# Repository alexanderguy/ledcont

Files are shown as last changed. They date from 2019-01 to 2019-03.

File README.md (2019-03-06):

# Dimming LED Controller

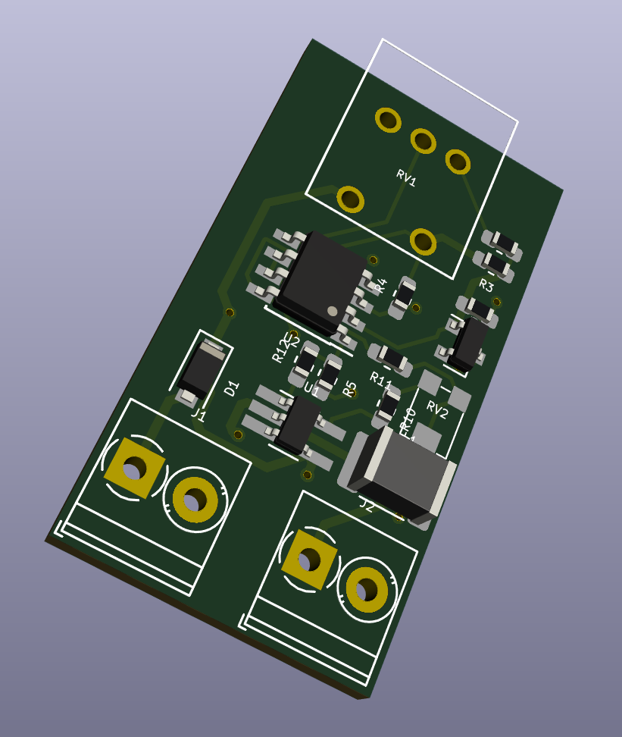
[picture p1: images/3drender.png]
3D Board Rendering


This is a basic dimming LED controller, designed for being run from one or more batteries (~3.25-6 volts).  It includes:

- Analog dimming.
- Low-voltage shutdown.
- Able to run at up to 1A.
- Two-layer board.

It takes about 1.5 hours to assemble if you're: building your first board, finding parts in the process, binging The Americans.

# Modifications

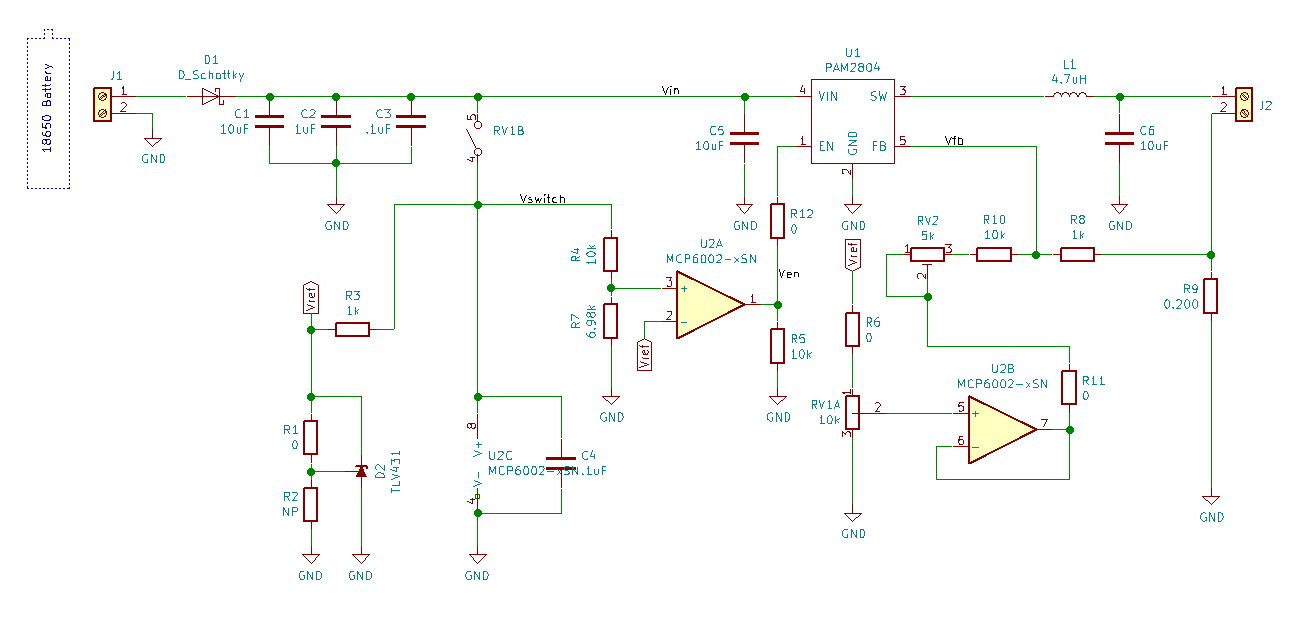
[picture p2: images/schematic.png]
Schematic Preview


There are a number of modifications possible:

- Change R4/R7 to provide the low-voltage shutdown point.
- Tune RV2/R10 to tweak the feedback offset.
- Set maximum current via R9 (see PAM2804 datasheet for more information).
- Don't populate D2/U2/RV1 (and supporting components) if dimming isn't needed (pull-up on EN needed).

# Wiring

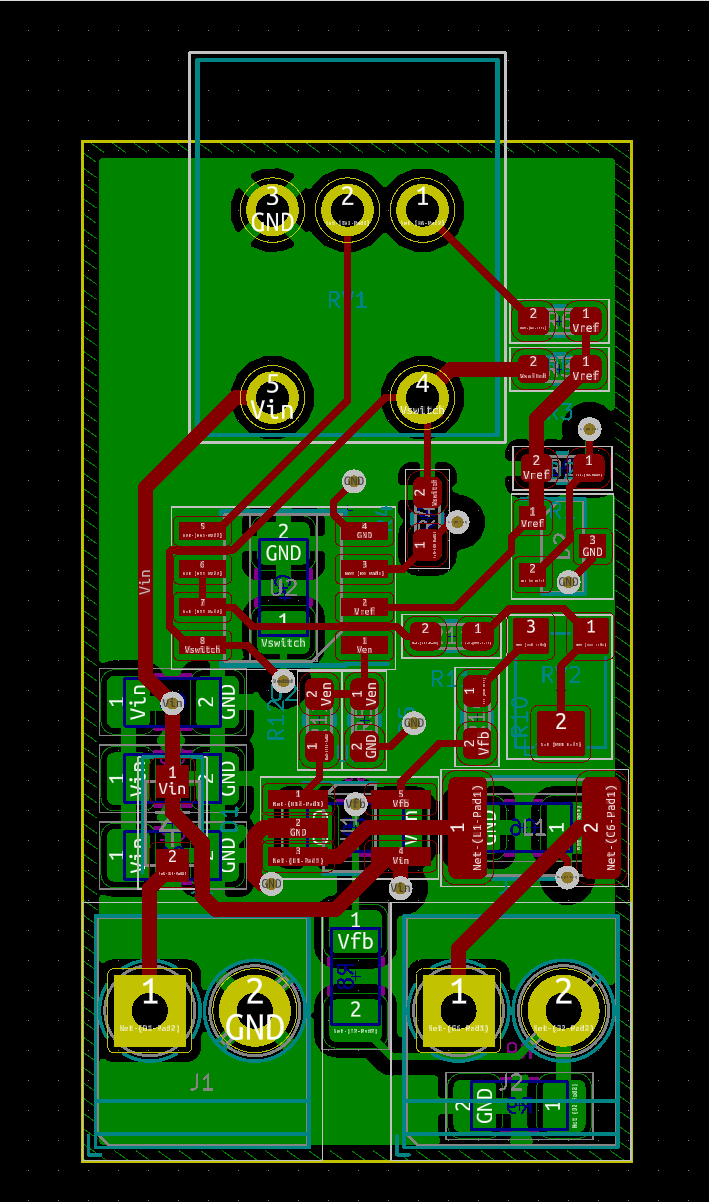
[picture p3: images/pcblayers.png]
PCB Layers


1. Make sure the switching potentiometer is turned off (i.e past the switch detent, counter-clockwise).
2. Attach your LED(s) to J2 Pin 1/+ and J2 Pin 2/-.
3. Attach your power supply to J1 Pin 1/+ and J1 Pin 2/-.

# Dimming Setup

1. Turn the potentiometer on, just past the switch detent.
2. Turn the potentiometer the opposite direction, until resistance is felt.  The LEDs might turn off.
3. If the LEDs are off, adjust RV2 until they are on.
4. If the LEDs were off, adjust RV2 until they just barely turn on.
5. Verify that the potentiometer now gives you complete brightness range for your LEDs.

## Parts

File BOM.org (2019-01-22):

* Possible Parts

| Qty | Part #          | Description                      |
|-----+-----------------+----------------------------------|
|   1 | PAM2804         | LED Driver                       |
|   1 | RL1206FR-070R2L | Current Sense Resistor           |
|   1 | P091S-FC20BR10K | 10k Potentiometer w/ SPST Switch |
|   1 | LQH43PN4R7M26L  | Inductor                         |
|   2 | 1984617         | 2 Pos Terminal Block             |

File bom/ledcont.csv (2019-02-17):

C1 | 10uF | Device:C | Capacitor_SMD:C_1206_3216Metric_Pad1.42x1.75mm_HandSolder | Unpolarized capacitor | CL31B106KOHNFNE
C2 | 1uF | Device:C | Capacitor_SMD:C_1206_3216Metric_Pad1.42x1.75mm_HandSolder | Unpolarized capacitor | CL31B105MAHNNNE
C3 | .1uF | Device:C | Capacitor_SMD:C_1206_3216Metric_Pad1.42x1.75mm_HandSolder | Unpolarized capacitor | CL31B104KBCNNNC
C4 | .1uF | Device:C | Capacitor_SMD:C_1206_3216Metric_Pad1.42x1.75mm_HandSolder | Unpolarized capacitor | CL31B104KBCNNNC
C5 | 10uF | Device:C | Capacitor_SMD:C_1206_3216Metric_Pad1.42x1.75mm_HandSolder | Unpolarized capacitor | CL31B106KOHNFNE
C6 | 10uF | Device:C | Capacitor_SMD:C_1206_3216Metric_Pad1.42x1.75mm_HandSolder | Unpolarized capacitor | CL31B106KOHNFNE
D1 | D_Schottky | Device:D_Schottky | Diode_SMD:D_SOD-123F | Schottky diode | NRVTS245ESFT1G
D2 | TLV431 | Reference_Voltage:TL431DBZ | Package_TO_SOT_SMD:SOT-23 | Shunt Regulator, SOT-23 | TLV431AFTA
J1 | Screw_Terminal_01x02 | Connector:Screw_Terminal_01x02 | TerminalBlock_Phoenix:TerminalBlock_Phoenix_PT-1,5-2-3.5-H_1x02_P3.50mm_Horizontal | Generic screw terminal, single row, 01x02, script generated (kicad-library-utils/schlib/autogen/connector/) | 1984617
J2 | Screw_Terminal_01x02 | Connector:Screw_Terminal_01x02 | TerminalBlock_Phoenix:TerminalBlock_Phoenix_PT-1,5-2-3.5-H_1x02_P3.50mm_Horizontal | Generic screw terminal, single row, 01x02, script generated (kicad-library-utils/schlib/autogen/connector/) | 1984617
L1 | 4.7uH | Device:L | Inductor_SMD:L_1812_4532Metric_Pad1.30x3.40mm_HandSolder | Inductor | LQH43PN4R7M26L
R1 | 0 | Device:R | Resistor_SMD:R_0603_1608Metric_Pad1.05x0.95mm_HandSolder | Resistor | RC0603FR-070RL
R2 | NP | Device:R | Resistor_SMD:R_0603_1608Metric_Pad1.05x0.95mm_HandSolder | Resistor
R3 | 1k | Device:R | Resistor_SMD:R_0603_1608Metric_Pad1.05x0.95mm_HandSolder | Resistor | RC0603FR-071KL
R4 | 10k | Device:R | Resistor_SMD:R_0603_1608Metric_Pad1.05x0.95mm_HandSolder | Resistor | RC0603FR-0710KL
R5 | 10k | Device:R | Resistor_SMD:R_0603_1608Metric_Pad1.05x0.95mm_HandSolder | Resistor | RC0603FR-0710KL
R6 | 0 | Device:R | Resistor_SMD:R_0603_1608Metric_Pad1.05x0.95mm_HandSolder | Resistor | RC0603FR-070RL
R7 | 6.98k | Device:R | Resistor_SMD:R_0603_1608Metric_Pad1.05x0.95mm_HandSolder | Resistor | RC0603FR-076K98L
R8 | 1k | Device:R | Resistor_SMD:R_1206_3216Metric_Pad1.42x1.75mm_HandSolder | Resistor | RC1206FR-071KL
R9 | 0.200 | Device:R | Resistor_SMD:R_1206_3216Metric_Pad1.42x1.75mm_HandSolder | Resistor | PT1206FR-070R2L
R10 | 10k | Device:R | Resistor_SMD:R_0603_1608Metric_Pad1.05x0.95mm_HandSolder | Resistor | RC0603FR-0710KL
R11 | 0 | Device:R | Resistor_SMD:R_0603_1608Metric_Pad1.05x0.95mm_HandSolder | Resistor | RC0603FR-070RL
R12 | 0 | Device:R | Resistor_SMD:R_0603_1608Metric_Pad1.05x0.95mm_HandSolder | Resistor | RC0603FR-070RL
RV1 | 10k | ledcont:R_POT_SPST | ledcont:P091_S | Potentiometer with Switch | P091S-FC20BR10K
RV2 | 5k | Device:R_POT_TRIM | ledcont:TC33X | Trim-potentiometer | TC33X-2-502E
U1 | PAM2804 | ledcont:PAM2804 | Package_TO_SOT_SMD:TSOT-23-5_HandSoldering |  | PAM2804AAB010
U2 | MCP6002-xSN | Amplifier_Operational:MCP6002-xSN | Package_SO:SOIC-8_3.9x4.9mm_P1.27mm | 1MHz, Low-Power Op Amp, SOIC-8 | MCP6002T-I/SN

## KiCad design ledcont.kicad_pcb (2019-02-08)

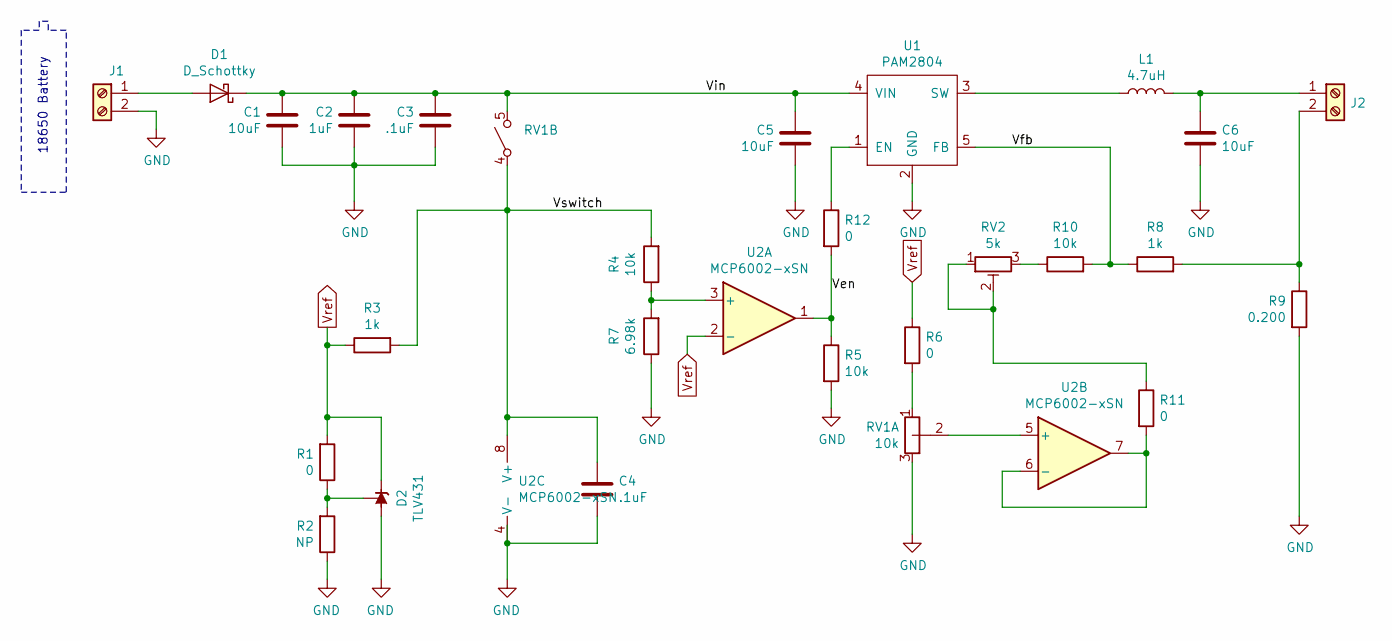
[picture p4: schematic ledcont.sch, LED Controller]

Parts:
C1, C5, C6: 10uF; C_1206_3216Metric_Pad1.42x1.75mm_HandSolder; Part CL31B106KOHNFNE
C2: 1uF; C_1206_3216Metric_Pad1.42x1.75mm_HandSolder; Part CL31B105MAHNNNE
C3, C4: .1uF; C_1206_3216Metric_Pad1.42x1.75mm_HandSolder; Part CL31B104KBCNNNC
D1: D_Schottky; D_SOD-123F; Part NRVTS245ESFT1G
D2: TLV431; SOT-23
J1, J2: Screw_Terminal_01x02; TerminalBlock_Phoenix_PT-1,5-2-3.5-H_1x02_P3.50mm_Horizontal; Part 1984617
L1: 4.7uH; L_1812_4532Metric_Pad1.30x3.40mm_HandSolder; Part LQH43PN4R7M26L
R1: 0; R_0603_1608Metric_Pad1.05x0.95mm_HandSolder; Tolerance 1%; Part RC0603FR-070RL
R2: NP; R_0603_1608Metric_Pad1.05x0.95mm_HandSolder; Tolerance 1%
R3: 1k; R_0603_1608Metric_Pad1.05x0.95mm_HandSolder; Tolerance 1%; Part RC0603FR-071KL
R4, R5, R10: 10k; R_0603_1608Metric_Pad1.05x0.95mm_HandSolder; Tolerance 1%; Part RC0603FR-0710KL
R6, R11, R12: 0; R_0603_1608Metric_Pad1.05x0.95mm_HandSolder; Part RC0603FR-070RL
R7: 6.98k; R_0603_1608Metric_Pad1.05x0.95mm_HandSolder; Tolerance 1%; Part RC0603FR-076K98L
R8: 1k; R_1206_3216Metric_Pad1.42x1.75mm_HandSolder; Tolerance 1%; Part RC1206FR-071KL
R9: 0.200; R_1206_3216Metric_Pad1.42x1.75mm_HandSolder; Tolerance 1%; Part PT1206FR-070R2L
RV1: 10k; P091_S; Part P091S-FC20BR10K
RV2: 5k; TC33X
U1: PAM2804; TSOT-23-5_HandSoldering; Part PAM2804AAB010
U2: MCP6002-xSN; SOIC-8_3.9x4.9mm_P1.27mm

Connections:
/Ven: R5.1, R12.2, U2.1
/Vfb: R8.1, R10.2, U1.5 (FB)
/Vin: C1.1, C2.1, C3.1, C5.1, D1.1 (K), RV1.5, U1.4 (VIN)
/Vswitch: C4.1, R3.2, R4.2, RV1.4, U2.8 (V+)
GND: C1.2, C2.2, C3.2, C4.2, C5.2, C6.2, D2.3 (A), J1.2, R2.1, R5.2, R7.1, R9.2, RV1.3, U1.2 (GND), U2.4 (V-)
unnamed: C6.1, J2.1, L1.2
unnamed: D1.2 (A), J1.1
unnamed: D2.2 (REF), R1.1, R2.2
unnamed: J2.2, R8.2, R9.1
unnamed: L1.1, U1.3 (SW)
unnamed: R4.1, R7.2, U2.3 (+)
unnamed: R6.2, RV1.1
unnamed: R10.1, RV2.3
unnamed: R11.1, RV2.1, RV2.2
unnamed: R11.2, U2.6 (-), U2.7
unnamed: R12.1, U1.1 (EN)
unnamed: RV1.2 (B), U2.5 (+)
Vref: D2.1 (K), R1.2, R3.1, R6.1, U2.2 (-)

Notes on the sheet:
18650 Battery

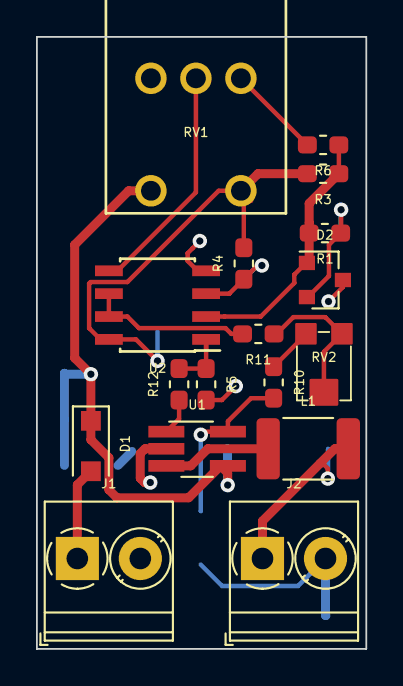
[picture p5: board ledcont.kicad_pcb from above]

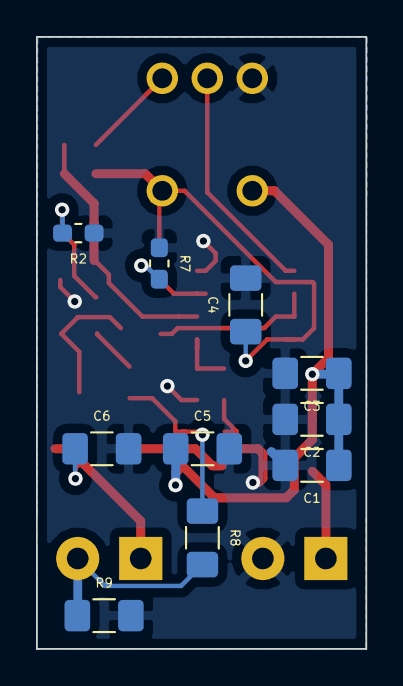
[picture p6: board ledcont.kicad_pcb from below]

Board: 2 copper layers, 18.3 x 34.0 mm, 27 parts (10 on the bottom side), 18 nets.

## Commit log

2019-01-11 Created a KiCad project.
    [ledcont.kicad_pcb, ledcont.sch]
2019-01-12 Continued work on the schematic.
2019-01-12 Started working on a bill of materials.
2019-01-22 Updated to the latest and greatest.
    [ledcont.sch]
2019-01-22 New footprint for PAM2804.
2019-01-22 Assigned footprints.
    [ledcont.sch]
2019-01-22 More progress.
    [ledcont.kicad_pcb, ledcont.sch]
2019-01-22 Updated footprints.
    [ledcont.kicad_pcb]
2019-01-22 Checkpoint before real board layout.
    [ledcont.kicad_pcb, ledcont.sch]
2019-01-23 Finished first attempt at board layout.
    [ledcont.kicad_pcb, ledcont.sch]
2019-01-23 Board cutout. Rewired unused comparator.
    [ledcont.kicad_pcb, ledcont.sch]
2019-01-28 Reverse potentionmeter usage so that the LEDs start out dimmed.
    [ledcont.kicad_pcb, ledcont.sch]
2019-01-28 Remove this note.
    [ledcont.sch]
2019-01-29 Switched PAM2804 to a standard TSOT-23-5 footprint.
    [ledcont.kicad_pcb, ledcont.sch]
2019-01-29 Remove our custom local footprint.
2019-02-07 Start transitioning to lower-voltage parts.
    [ledcont.kicad_pcb, ledcont.sch]
2019-02-08 Added the TC33X trimmer pot footprint.
2019-02-08 More board updates.
    [ledcont.kicad_pcb, ledcont.sch]
2019-02-08 More work to get things ordered. Updated the BoM.
    [ledcont.kicad_pcb, ledcont.sch]
2019-02-08 Updated the schematic. Fixed missing PNs.
    [ledcont.sch]
2019-02-17 Brought some of these from the kicad release so we can tweak them.
2019-02-17 Commit this generated output for ease of use.
    [ledcont.csv]
2019-02-17 Provide a schematic preview.
2019-02-17 Embed the schematic image.
2019-02-17 Compensate for D1's forward drop.
    [ledcont.sch]
2019-02-17 Add part vendors.
    [ledcont.sch]
2019-03-06 Fix vendors.
    [ledcont.sch]
